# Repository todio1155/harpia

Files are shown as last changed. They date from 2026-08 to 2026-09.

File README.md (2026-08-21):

# HARPIA NINHO: introdução

Projeto "Harpia Ninho" é uma impressora 3D projetada para ser open-source (leia a licença atual do projeto antes de usar), durável, modificável e atualmente ficando mais fácil de consertar e fazer módulos de expansão, tipo um LAN/Ethernet, mais NTC, driver de passo, FRAM e muito mais. Ele foi feito para ATX-20 ou ATX-24; licença "CERN-OHL-S-2.0".
## contexto
Eu queria uma impressora 3D barata, eficiente, personalizada e open-source que pudesse ser muito modificada. 

## pré requisitos
[kicad 10.0 ou maior](https://www.kicad.org/download/)

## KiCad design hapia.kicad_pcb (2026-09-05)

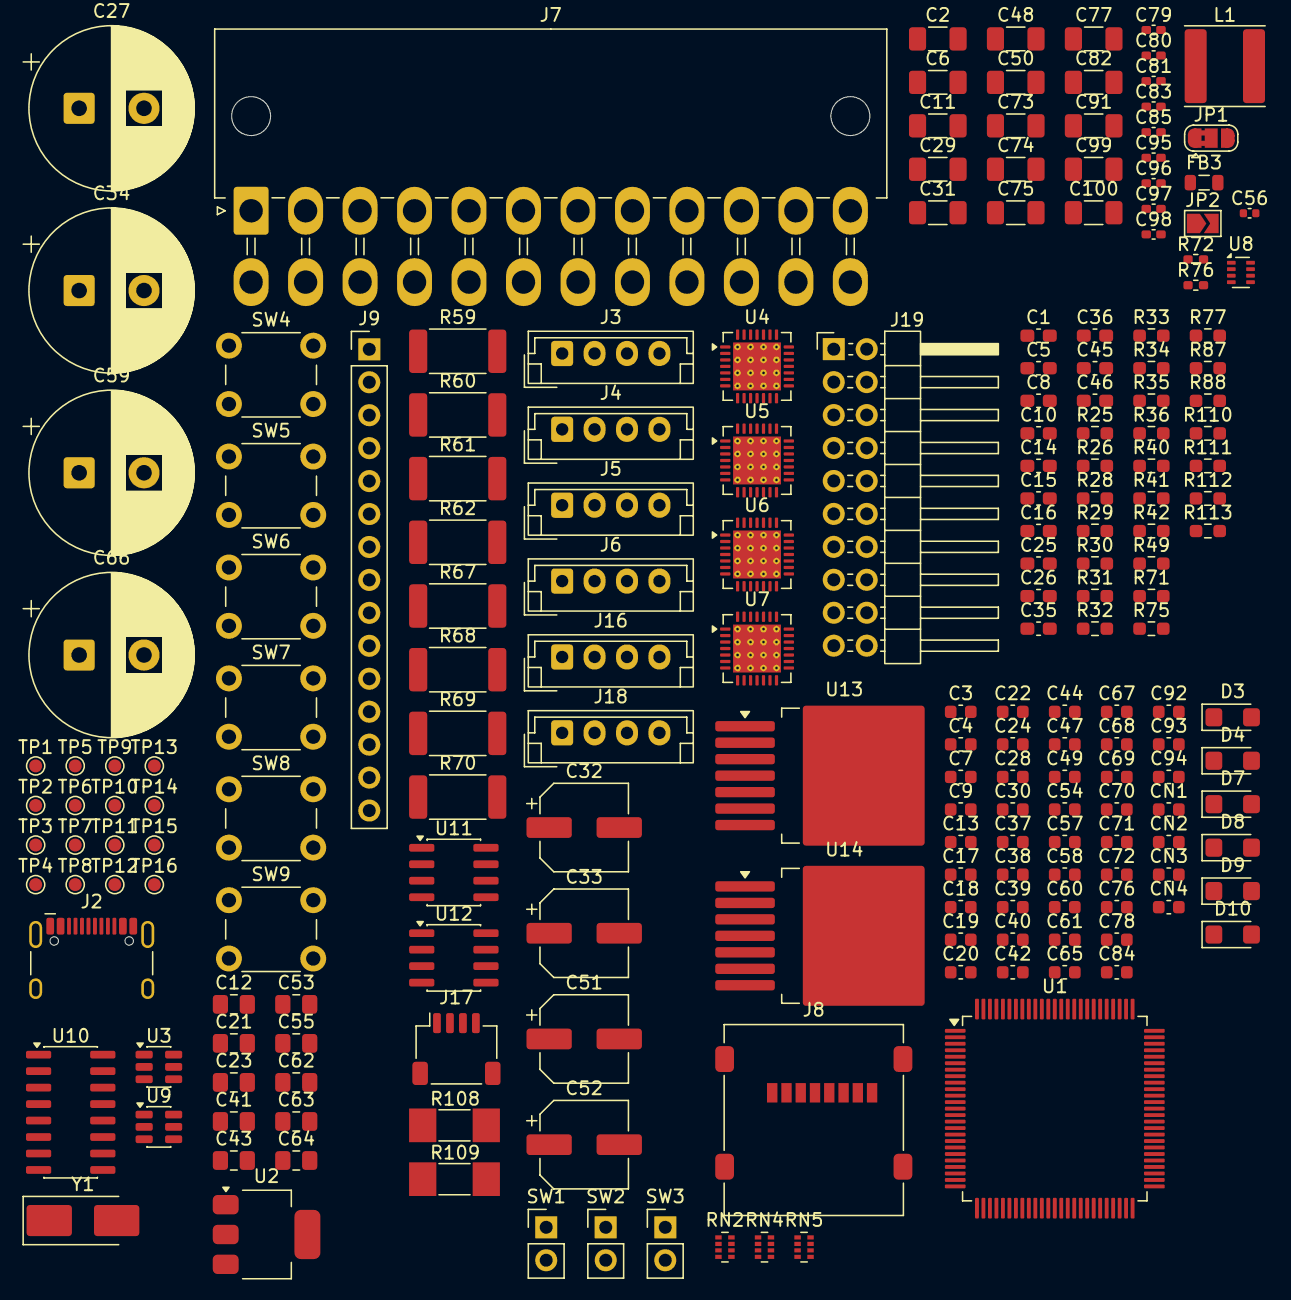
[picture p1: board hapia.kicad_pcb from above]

Board: 6 copper layers, 200 parts (0 on the bottom side), 149 nets, no tracks yet.

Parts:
C1, C5: 22pf; C_0603_1608Metric_Pad1.08x0.95mm_HandSolder
C2, C6, C11, C29, C31, C48, C50, C73, C74, C75, C77, C82, C91, C99, C100: 10µf; C_1206_3216Metric_Pad1.33x1.80mm_HandSolder
C3, C4, C7, C9, C13, C17, C18, C19, C20, C22, C24, C28, C30, C37, C38, C39, C40, C42, C44, C47, C49, C54, C57, C58, C60, C61, C65, C67, C68, C69, C70, C71, C72, C76, C78, C84, C92, C93, C94: 100nf; C_0603_1608Metric
C8, C10, C14, C25, C26, C45, C46: 4.7µf; C_0603_1608Metric_Pad1.08x0.95mm_HandSolder
C12, C21, C23, C41, C43, C63: 1µf; C_0805_2012Metric_Pad1.18x1.45mm_HandSolder
C15, C16, C35, C36: 22nf; C_0603_1608Metric_Pad1.08x0.95mm_HandSolder
C27, C34, C59, C66: 1000µf; CP_Radial_D12.5mm_P5.00mm
C32, C33, C51, C52: 100µf; CP_Elec_6.3x7.7
C53, C55, C62, C64: 22µf; C_0805_2012Metric_Pad1.18x1.45mm_HandSolder
C56: 33nf; C_0402_1005Metric
C79, C80, C81, C83, C85, C95, C96, C97, C98: 10nf; C_0402_1005Metric_Pad0.74x0.62mm_HandSolder
CN1, CN2, CN3, CN4: 100nf; C_0603_1608Metric
D3: SMF5V0A; D_SMF
D4, D7, D8, D9: SMF3.3; D_SMF
D10: SMF12A; D_SMF
FB3: FerriteBead; L_0805_2012Metric
J2: USB_C_Receptacle_USB2.0_16P; USB_C_Receptacle_HCTL_HC-TYPE-C-16P-01A
J3, J4, J5, J6, J16, J18: Conn_01x04_Pin; JST_EH_B4B-EH-A_1x04_P2.50mm_Vertical
J7: ATX-24; Molex_Mini-Fit_Jr_5569-24A2_2x12_P4.20mm_Horizontal
J8: Micro_SD_Card; microSD_HC_Molex_47219-2001
J9: Conn_01x15_Pin; PinHeader_1x15_P2.54mm_Vertical
J17: Conn_01x04_MountingPin; JST_SH_SM04B-SRSS-TB_1x04-1MP_P1.00mm_Horizontal
J19: ETH; PinHeader_2x10_P2.54mm_Horizontal
JP1: usb/atx; SolderJumper-3_P1.3mm_Bridged2Bar12_RoundedPad1.0x1.5mm
JP2: fre; SolderJumper-2_P1.3mm_Open_TrianglePad1.0x1.5mm
L1: 4.7µh; L_Changjiang_FNR6020S
R25, R26: 22Ω; R_0603_1608Metric_Pad0.98x0.95mm_HandSolder
R28, R29, R30, R31, R32, R33, R34, R35, R36, R40, R41, R42, R49, R75, R110, R111, R112, R113: 33Ω; R_0603_1608Metric_Pad0.98x0.95mm_HandSolder
R59, R60, R61, R62, R67, R68, R69, R70: 100mΩ; R_2512_6332Metric_Pad1.40x3.35mm_HandSolder
R71: 100kΩ; R_0603_1608Metric_Pad0.98x0.95mm_HandSolder
R72: 57.6kΩ; R_0402_1005Metric_Pad0.72x0.64mm_HandSolder
R76: 330Ω; R_0402_1005Metric_Pad0.72x0.64mm_HandSolder
R77: 30.9kΩ; R_0603_1608Metric_Pad0.98x0.95mm_HandSolder
R87, R88: 4.7kΩ; R_0603_1608Metric_Pad0.98x0.95mm_HandSolder
R108, R109: 12Ω; R_MELF_MMB-0207
RN2, RN4, RN5: 33Ω; R_Array_Concave_4x0402
SW1, SW2, SW3: SW_Push; PinHeader_1x02_P2.54mm_Vertical
SW4, SW5, SW6, SW7, SW8, SW9: SW_P; SW_PUSH_6mm_H5mm
TP1, TP2, TP4, TP13: TestPoint; TestPoint_Pad_D1.0mm
TP3, TP16: 3.3v; TestPoint_Pad_D1.0mm
TP5, TP6, TP9, TP10: 3.3v_power; TestPoint_Pad_D1.0mm
TP7, TP8, TP11, TP12: 12v_power; TestPoint_Pad_D1.0mm
TP14: 12v; TestPoint_Pad_D1.0mm
TP15: 5v; TestPoint_Pad_D1.0mm
U1: STM32F407VET6; LQFP-100_14x14mm_P0.5mm
U2: AMS1117-3.3; SOT-223-3_TabPin2
U3, U9: SRV05-4HTG-D; SOT-23-6
U4, U5, U6, U7: TMC2209-LA; VQFN-28-1EP_5x5mm_P0.5mm_EP3.7x3.7mm_ThermalVias
U8: TPS62933F; SOT-583-8
U10: 74HC4051; SOIC-16_3.9x9.9mm_P1.27mm
U11, U12: UCC27524DR; SOIC-8_3.9x4.9mm_P1.27mm
U13, U14: IRFS7530TRL7PP; TO-263-7_TabPin4
Y1: 8mhz; Crystal_SMD_5032-2Pin_5.0x3.2mm_HandSoldering

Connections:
3.3v/1: C2.1, CN1.1 (common), CN1.2 (C1), CN2.2 (C1), JP1.2 (C), TP3.1 (1_1), U1.6 (VBAT), U1.11 (VDD), U1.19 (VDD), U1.28 (VDD), U1.50 (VDD), U1.75 (VDD), U1.100 (VDD)
+3.3V: C61.1, C62.1, C64.1, C70.1, C73.1, C76.1, C77.1, C78.1, C82.1, C91.1, C92.2, D4.1 (A1), J8.4 (VDD), J16.1, J17.1, J18.1, JP1.3 (B), L1.2, R76.1, R87.1, R88.1, SW4.2, SW5.2, SW6.2, SW7.2, SW8.2, SW9.2, TP16.1 (1_1), U9.2 (VN), U10.16 (VCC), U11.6 (V_{DD}), U12.6 (V_{DD})
+3.3Vdev: C12.1, D9.1 (A1), JP1.1 (A), U2.2 (VO)
+3V3: C13.1, C14.1, C19.2, C20.2, C21.2, C23.2, C38.2, C40.2, C41.2, C43.2, TP5.1 (1_1), TP6.1 (1_1), TP9.1 (1_1), TP10.1 (1_1), U4.15 (VCC_IO), U5.9 (MS1/AD0), U5.15 (VCC_IO), U6.10 (MS2/AD1), U6.15 (VCC_IO), U7.9 (MS1/AD0), U7.10 (MS2/AD1), U7.15 (VCC_IO)
+5V: C60.1, C63.1, C71.1, C74.1, J9.13, TP15.1 (1_1)
+5VSB: C57.1, FB3.2, J9.2
+5Vusb: C11.1, U2.3 (VI)
+12P: C18.1, C28.2, C29.2, C30.2, C31.2, C32.1, C33.1, C47.2, C48.2, C49.2, C50.2, C51.1, C52.1, TP7.1 (1_1), TP8.1 (1_1), TP11.1 (1_1), TP12.1 (1_1), U4.22 (VS), U4.28 (VS), U5.22 (VS), U5.28 (VS), U6.22 (VS), U6.28 (VS), U7.22 (VS), U7.28 (VS)
+12V: C27.1, C34.1, C59.1, C65.1, C66.1, C67.1, C68.1, C69.1, C72.1, C75.1, D10.1 (A1), J9.15, TP14.1 (1_1), U11.2 (INA), U11.4 (INB), U12.2 (INA), U12.4 (INB)
/RMII_expansão/vcc_RMII: C99.1, C100.1, CN3.1 (common), CN3.2 (C1), D7.1 (A1)
ATX_PWR_o: D8.1 (A1), U1.97 (PE0)
CLK_0: C1.1, U1.12 (PH0), Y1.2
CLK_X: C5.1, U1.13 (PH1), Y1.1
Fan_1: U1.46 (PE15), U11.1 (ENA)
Fan_2: U1.43 (PE12), U11.8 (ENB)
GND: C1.2, C2.2, C3.2, C4.2, C5.2, C6.2, C7.2, C8.2, C9.2, C10.2, C11.2, C12.2, C13.2, C14.2, C17.1, C19.1, C20.1, C21.1, C22.1, C23.1, C24.1, C25.1, C26.1, C27.2, C28.1, C29.1, C30.1, C31.1, C32.2, C33.2, C34.2, C37.1, C38.1, C39.1, C40.1, C41.1, C42.1, C43.1, C44.1, C45.1, C46.1, C47.1, C48.1, C49.1, C50.1, C51.2, C52.2, C53.2, C54.2, C55.2, C56.2, C57.2, C59.2, C60.2, C61.2, C62.2, C63.2, C64.2, C65.2, C66.2, C67.2, C70.2, C71.2, C72.2, C73.2, C74.2, C75.2, C76.2, C77.2, C78.2, C79.2, C80.2, C81.2, C82.2, C83.2, C84.2, C85.2, C91.2, C92.1, C93.2, C94.2, C95.2, C96.2, C97.2, C98.2, C99.2, C100.2, D3.2 (A2), D4.2 (A2), D7.2 (A2), D8.2 (A2), D9.2 (A2), D10.2 (A2), J2.A1 (GND), J2.A12 (GND), J2.B1 (GND), J2.B12 (GND), J7.3 (GND), J7.5 (GND), J7.7 (GND), J7.15 (GND), J7.17 (GND), J7.18 (GND), J7.19 (GND), J7.24 (GND), J9.1, J9.3, J9.12, J16.2, J17.2, J17.MP (MountPin), J18.2, JP2.1 (A), R59.2, R60.2, R61.2, R62.2, R67.2, R68.2, R69.2, R70.2, R72.2, SW1.1, SW2.1, SW3.2, U1.10 (VSS), U1.20 (VSSA), U1.27 (VSS), U1.74 (VSS), U1.99 (VSS), U2.1 (GND), U3.5 (VP), U4.3 (GND), U4.9 (MS1/AD0), U4.10 (MS2/AD1), U4.13 (CLK), U4.18 (GND), U4.20 (STDBY), U4.29 (GND), U5.3 (GND), U5.10 (MS2/AD1), U5.13 (CLK), U5.18 (GND), U5.20 (STDBY), U5.29 (GND), U6.3 (GND), U6.9 (MS1/AD0), U6.13 (CLK), U6.18 (GND), U6.20 (STDBY), U6.29 (GND), U7.3 (GND), U7.13 (CLK), U7.18 (GND), U7.20 (STDBY), U7.29 (GND), U8.4 (GND), U9.5 (VP), U10.7 (VEE), U10.8 (GND), U11.3 (GND), U12.3 (GND), U13.2 (S), U13.3 (S), U13.5 (S), U13.6 (S), U13.7 (S), U14.2 (S), U14.3 (S), U14.5 (S), U14.6 (S), U14.7 (S)
MUX_EN: U1.98 (PE1), U10.6 (~E)
NTC_EX: C79.1, U10.13 (A0)
NTC_MUX_0: U1.3 (PE4), U10.11 (S0)
NTC_MUX_1: U1.4 (PE5), U10.10 (S1)
NTC_MUX_2: U1.5 (PE6), U10.9 (S2)
NTC_MUX_out: U1.15 (PC0), U10.3 (A)
NTC_driver_1: C81.1, U10.1 (A4)
NTC_driver_2: C96.1, U10.5 (A5)
NTC_driver_3: C97.1, U10.2 (A6)
NTC_driver_4: C98.1, U10.4 (A7)
NTC_ht: C80.1, U10.14 (A1)
NTC_mosfet_1: C83.1, U10.15 (A2)
NTC_mosfet_2: C95.1, U10.12 (A3)
unnamed: J2.A4 (VBUS), J2.A9 (VBUS), J2.B4 (VBUS), J2.B9 (VBUS), TP4.1 (1_1), U3.2 (VN)
unnamed: D3.1 (A1), FB3.1
unnamed: J7.4 (+5V), J7.6 (+5V), J7.21 (+5V), J7.22 (+5V), J7.23 (+5V)
unnamed: J3.1, U4.1 (OB2)
unnamed: J3.2, U4.26 (OB1)
unnamed: J3.3, U4.21 (OA2)
unnamed: J3.4, U4.24 (OA1)
unnamed: J4.1, U5.1 (OB2)
unnamed: J4.2, U5.26 (OB1)
unnamed: J4.3, U5.21 (OA2)
unnamed: J4.4, U5.24 (OA1)
unnamed: J5.1, U6.1 (OB2)
unnamed: J5.2, U6.26 (OB1)
unnamed: J5.3, U6.21 (OA2)
unnamed: J5.4, U6.24 (OA1)
unnamed: J6.1, U7.1 (OB2)
unnamed: J6.2, U7.26 (OB1)
unnamed: J6.3, U7.21 (OA2)
unnamed: J6.4, U7.24 (OA1)
unnamed: JP2.2 (B), U8.1 (RT)
unnamed: R76.2, R77.1
unnamed: RN5.1 (R1.1), U1.38 (PE7)
unnamed: RN5.2 (R2.1), U1.39 (PE8)
unnamed: RN5.3 (R3.1), U1.40 (PE9)
unnamed: RN5.4 (R4.1), U1.41 (PE10)
unnamed: R49.1, U1.23 (PA0)
unnamed: R75.1, U1.25 (PA2)
unnamed: R110.1, U1.26 (PA3)
unnamed: R111.1, U1.29 (PA4)
unnamed: R112.1, U1.30 (PA5)
unnamed: R113.1, U1.31 (PA6)
unnamed: R40.1, U1.72 (PA13)
unnamed: R41.1, U1.76 (PA14)
unnamed: R32.1, U1.89 (PB3)
unnamed: R33.1, U1.90 (PB4)
unnamed: R36.1, U1.91 (PB5)
unnamed: R29.1, U1.48 (PB11)
unnamed: R30.1, U1.51 (PB12)
unnamed: R31.1, U1.52 (PB13)
unnamed: R34.1, U1.78 (PC10)
unnamed: R35.1, U1.79 (PC11)
unnamed: R28.1, U1.88 (PD7)
unnamed: R25.1, U1.61 (PD14)
unnamed: R26.1, U1.62 (PD15)
unnamed: R42.1, U1.42 (PE11)
unnamed: C7.1, C8.1, U1.49 (VCAP_1)
unnamed: C9.1, C10.1, U1.73 (VCAP_2)
unnamed: C22.2, C25.2, U4.8 (5VOUT)
unnamed: R61.1, U4.23 (BRA)
unnamed: R59.1, U4.27 (BRB)
unnamed: C15.2, U4.5 (CPI)
unnamed: C15.1, U4.4 (CPO)
unnamed: C17.2, U4.6 (VCP)
unnamed: C24.2, C26.2, U5.8 (5VOUT)
unnamed: R62.1, U5.23 (BRA)
unnamed: R60.1, U5.27 (BRB)
unnamed: C16.2, U5.5 (CPI)
unnamed: C16.1, U5.4 (CPO)
unnamed: C18.2, U5.6 (VCP)
unnamed: C42.2, C45.2, U6.8 (5VOUT)
unnamed: R69.1, U6.23 (BRA)
unnamed: R67.1, U6.27 (BRB)
unnamed: C35.2, U6.5 (CPI)
unnamed: C35.1, U6.4 (CPO)
unnamed: C39.2, U6.6 (VCP)
unnamed: C44.2, C46.2, U7.8 (5VOUT)
unnamed: R70.1, U7.23 (BRA)
unnamed: R68.1, U7.27 (BRB)
unnamed: C36.2, U7.5 (CPI)
unnamed: C36.1, U7.4 (CPO)
unnamed: C37.2, U7.6 (VCP)
unnamed: C58.1, U8.6 (BST)
unnamed: R71.2, R72.1, U8.2 (EN)
unnamed: R77.2, U8.8 (FB)
unnamed: C56.1, U8.7 (SS)
unnamed: C58.2, L1.1, U8.5 (SW)
unnamed: C53.1, C54.1, C55.1, R71.1, U8.3 (VIN)
unnamed: R108.1, U12.7 (OUTA)
unnamed: R109.1, U12.5 (OUTB)
unnamed: R108.2, U13.1 (G)
unnamed: R109.2, U14.1 (G)
STM_boot: C4.1, SW2.2, TP1.1 (1_1), U1.94 (BOOT0)
STM_nrst: C3.1, SW1.2, TP2.1 (1_1), U1.14 (NRST)
SUB_1: J7.16 (PS_ON#), SW3.1, TP13.1 (1_1), U1.60 (PD13)
SUB_6: U1.1 (PE2), U1.55 (PD8)
SUB_SCL: R88.2, U1.92 (PB6)
SUB_SDA: R87.2, U1.93 (PB7)
S_1: CN4.1 (common), SW4.1
S_2: CN4.2 (C1), SW6.1
S_3: C93.1, SW8.1
S_6: C94.1, SW9.1
S_SCL: J16.3, J17.3, J18.3
S_SDA: J16.4, J17.4, J18.4
TMC_DIR_1: R75.2, U4.19 (DIR)
TMC_DIR_2: R111.2, U6.19 (DIR)
TMC_DIR_3: R113.2, RN5.7 (R2.2), U5.19 (DIR)
TMC_DIR_4: R42.2, U7.19 (DIR)
TMC_step_1: R110.2, U4.16 (STEP)
TMC_step_2: R112.2, U6.16 (STEP)
TMC_step_3: RN5.6 (R3.2), RN5.8 (R1.2), U5.16 (STEP)
TMC_step_4: RN5.5 (R4.2), U7.16 (STEP)
TMC_uart: R49.2, U4.14 (~PD/UART), U5.14 (~PD/UART), U6.14 (~PD/UART), U7.14 (~PD/UART)
USB_C_D+: J2.A6 (D+), J2.B6 (D+), R26.2, U3.4 (IO3)
USB_C_D-: J2.A7 (D-), J2.B7 (D-), R25.2, U3.6 (IO4)
VDDA: C6.1, C84.1, CN2.1 (common), U1.21 (VREF+), U1.22 (VDDA)
exrtusora: U1.44 (PE13), U12.8 (ENB)
gpi_PD0: J9.11, R34.2
gpi_PD1: J9.10, RN2.1 (R1.1)
gpi_PD2: J9.9, R35.2
gpi_PD3: J9.8, RN2.2 (R2.1)
gpi_PD4: J9.7, RN2.3 (R3.1)
gpi_PD5: J9.6, RN2.4 (R4.1)
gpi_PD6: J9.5, RN2.5 (R5.1)
gpi_PD7: J9.4, RN2.6 (R6.1)
hot_bed: U1.45 (PE14), U12.1 (ENA)
hotbed: J7.10 (+12V), J7.11 (+12V)
sd_SCK: J8.5 (CLK), RN4.5 (R5.1), U9.1 (IO1)
sd_cs: J8.2 (DAT3/CD), RN4.8 (R8.1), U9.6 (IO4)
sd_miso: J8.7 (DAT0), RN4.6 (R6.1), U9.3 (IO2)
sd_mosi: J8.3 (CMD), RN4.7 (R7.1), U9.4 (IO3)

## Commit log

2026-05-15 Add files via upload
    base
    [hapia.kicad_pcb, hapia.kicad_sch, untitled.kicad_sch]
2026-06-01 Add files via upload
    V0,5
    [hapia (1).kicad_sch]
2026-07-29 revisão 29072026 kicad 10
    mais robusta, completa e mais perto de um lançamento funcional
    [hapia.kicad_sch, motor_passo.kicad_sch, potencia_misc.kicad_sch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]
2026-08-10 10082026/B
    nova revisão
    [hapia.kicad_sch, motor_passo.kicad_sch, potencia_misc.kicad_sch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]
2026-08-10 10082026/D
    "erros bobos"
    [hapia.kicad_sch, potencia_misc.kicad_sch, sub_interfaz.kicad_sch]
2026-08-17 17082026/E
    modulo FRAM e Melhoria no esquemático
    [d-nmos.kicad_sch, hapia.kicad_sch, motor_passo.kicad_sch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]
2026-08-21 21082026/G
    falta muita coisa
    [d-nmos.kicad_sch, hapia.kicad_pcb, hapia.kicad_sch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]
2026-09-01 o .bom não foi terminado
    O desafio e todo custar menos de 150 dólares(eua) e menos de 1000r(reais)
    [hapia.kicad_pcb, hapia.kicad_sch, motor_passo.kicad_sch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]
2026-09-01 01092026/AA
    O desafio e todo custar menos de 150 dólares(ela) e menos de 1000r(reais)
